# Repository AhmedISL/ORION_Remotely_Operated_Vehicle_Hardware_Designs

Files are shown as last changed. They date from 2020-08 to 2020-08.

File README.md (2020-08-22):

# ORION Remotely Operated Vehicle Hardware Design

These are the printed circuit boards (PCBs) designed for controlling the Remotely Operated Vehicle (ROV) which participated in the MATE international ROV competition 2019 and won the 7th place internationally and the 1st place locally and regionally.

## The electrical system is integrated using 4 main PCBs:
> ###### 1- **2** PCBs for the power management.
> ###### 2- **2** PCBs for the communication system and actuators' control.

***Power management PCBs' specifications:***
> ###### 1- Single layer.
> ###### 2- Voltage input range from 48V to 36V. 
> ###### 3- Over-current, voltage and thermal safety system

***Communication and actuators' control PCBs' specification:***
> ###### 1- Single layer.
> ###### 2- Voltage input range from 12V to 9V.
> ###### 3- The required voltage output with 99% efficiency
> ###### 4- Data transferring capability over Bluetooth/USB serial.

# Electronics' Enclosure Assembly
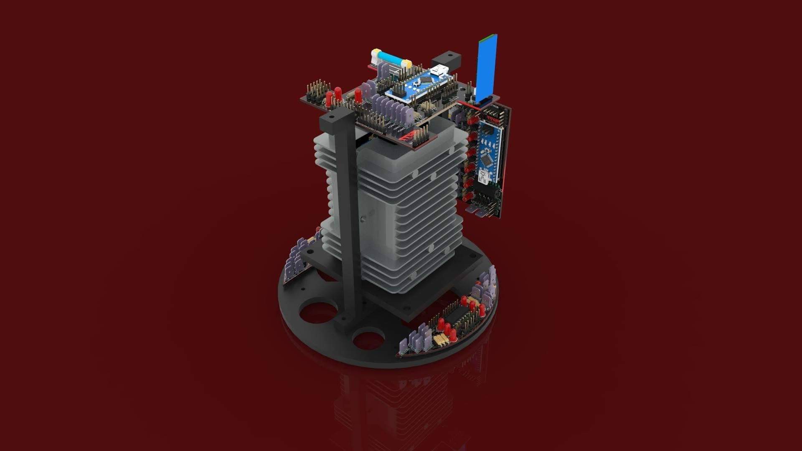
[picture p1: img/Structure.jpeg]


# Board I
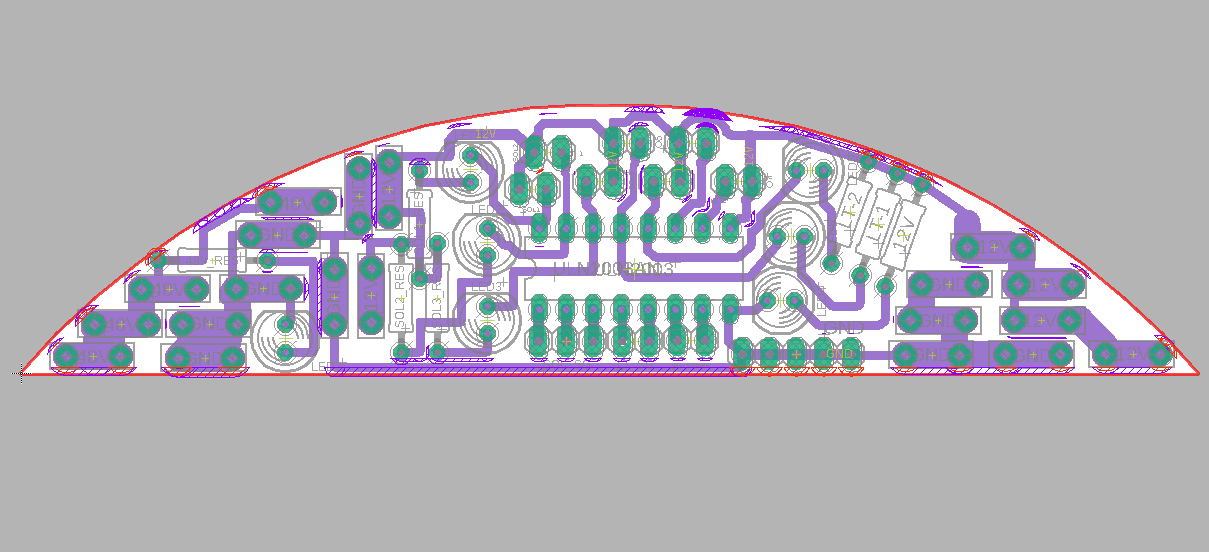
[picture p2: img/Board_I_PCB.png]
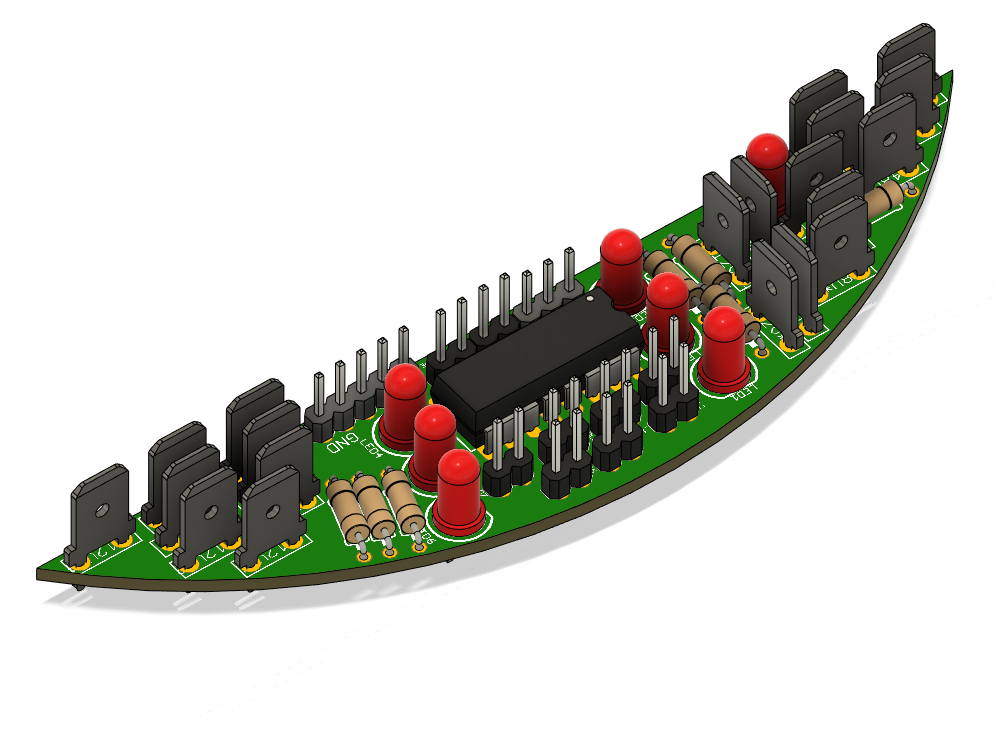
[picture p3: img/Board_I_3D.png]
 

# Board II
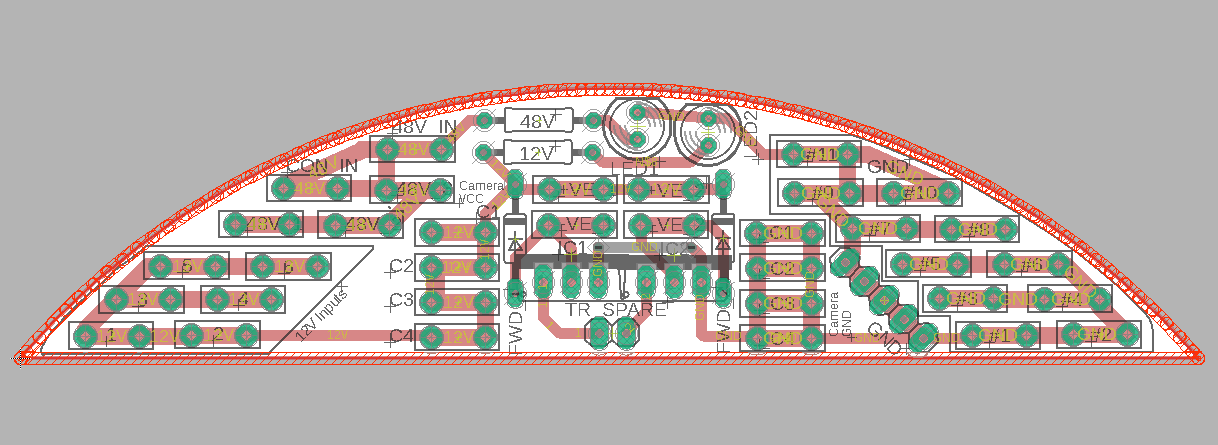
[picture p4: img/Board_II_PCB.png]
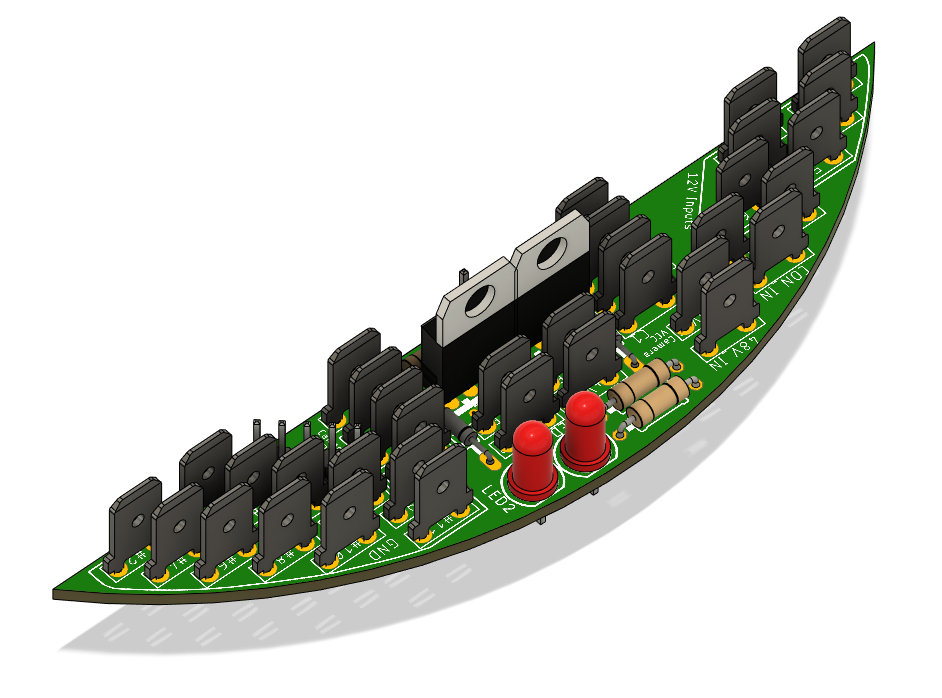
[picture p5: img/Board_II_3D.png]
 

# Board 2
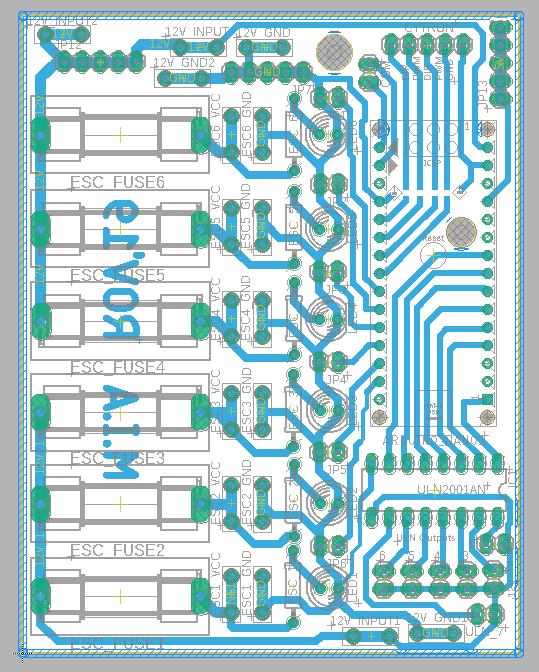
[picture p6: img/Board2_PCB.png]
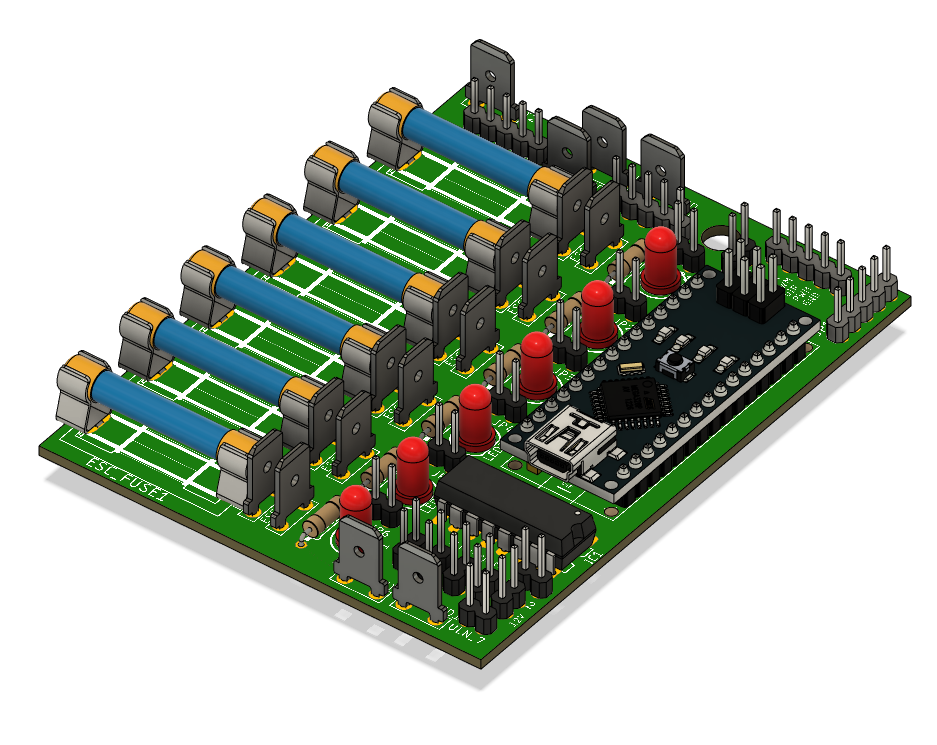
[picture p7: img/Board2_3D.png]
 

# Board 3
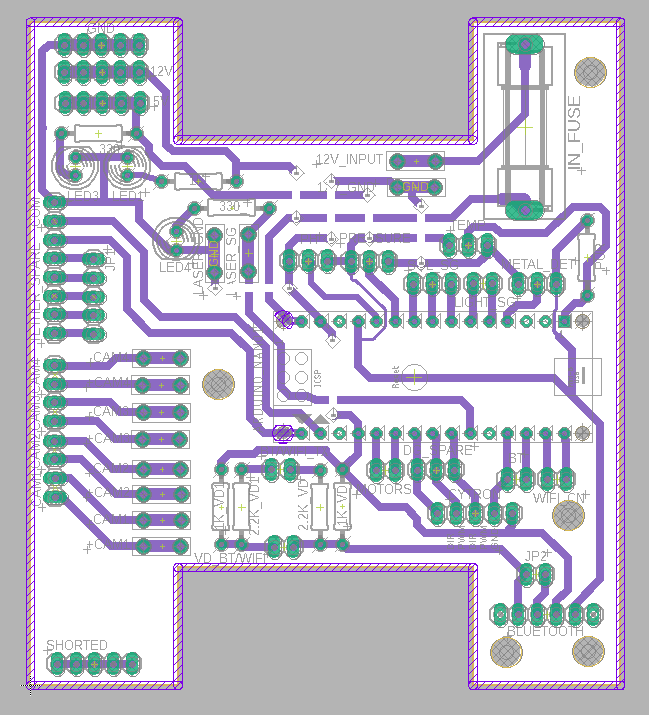
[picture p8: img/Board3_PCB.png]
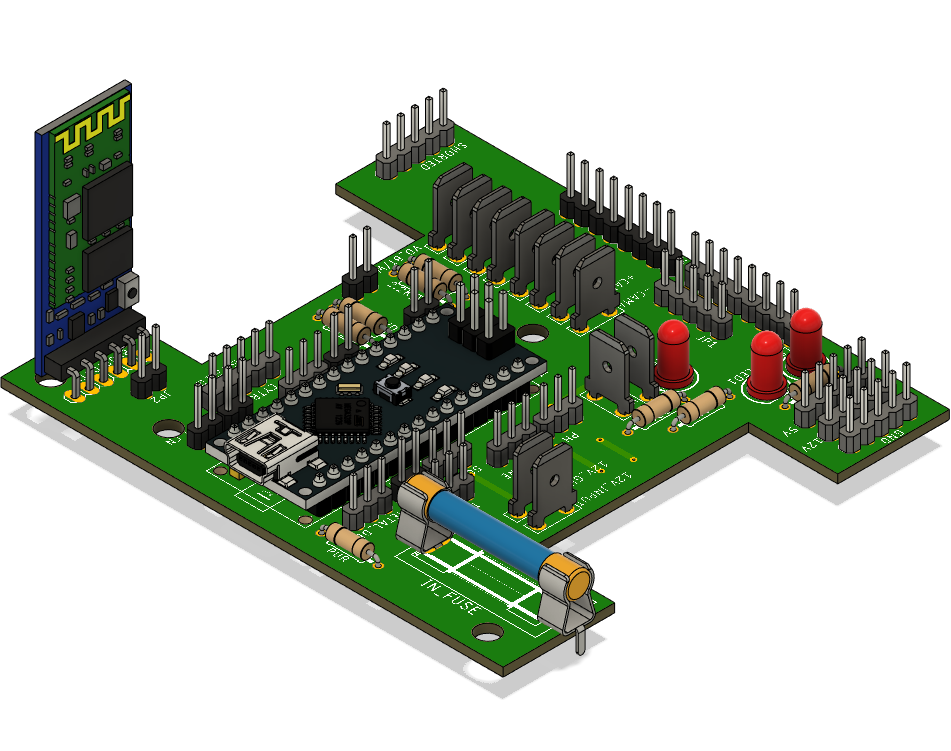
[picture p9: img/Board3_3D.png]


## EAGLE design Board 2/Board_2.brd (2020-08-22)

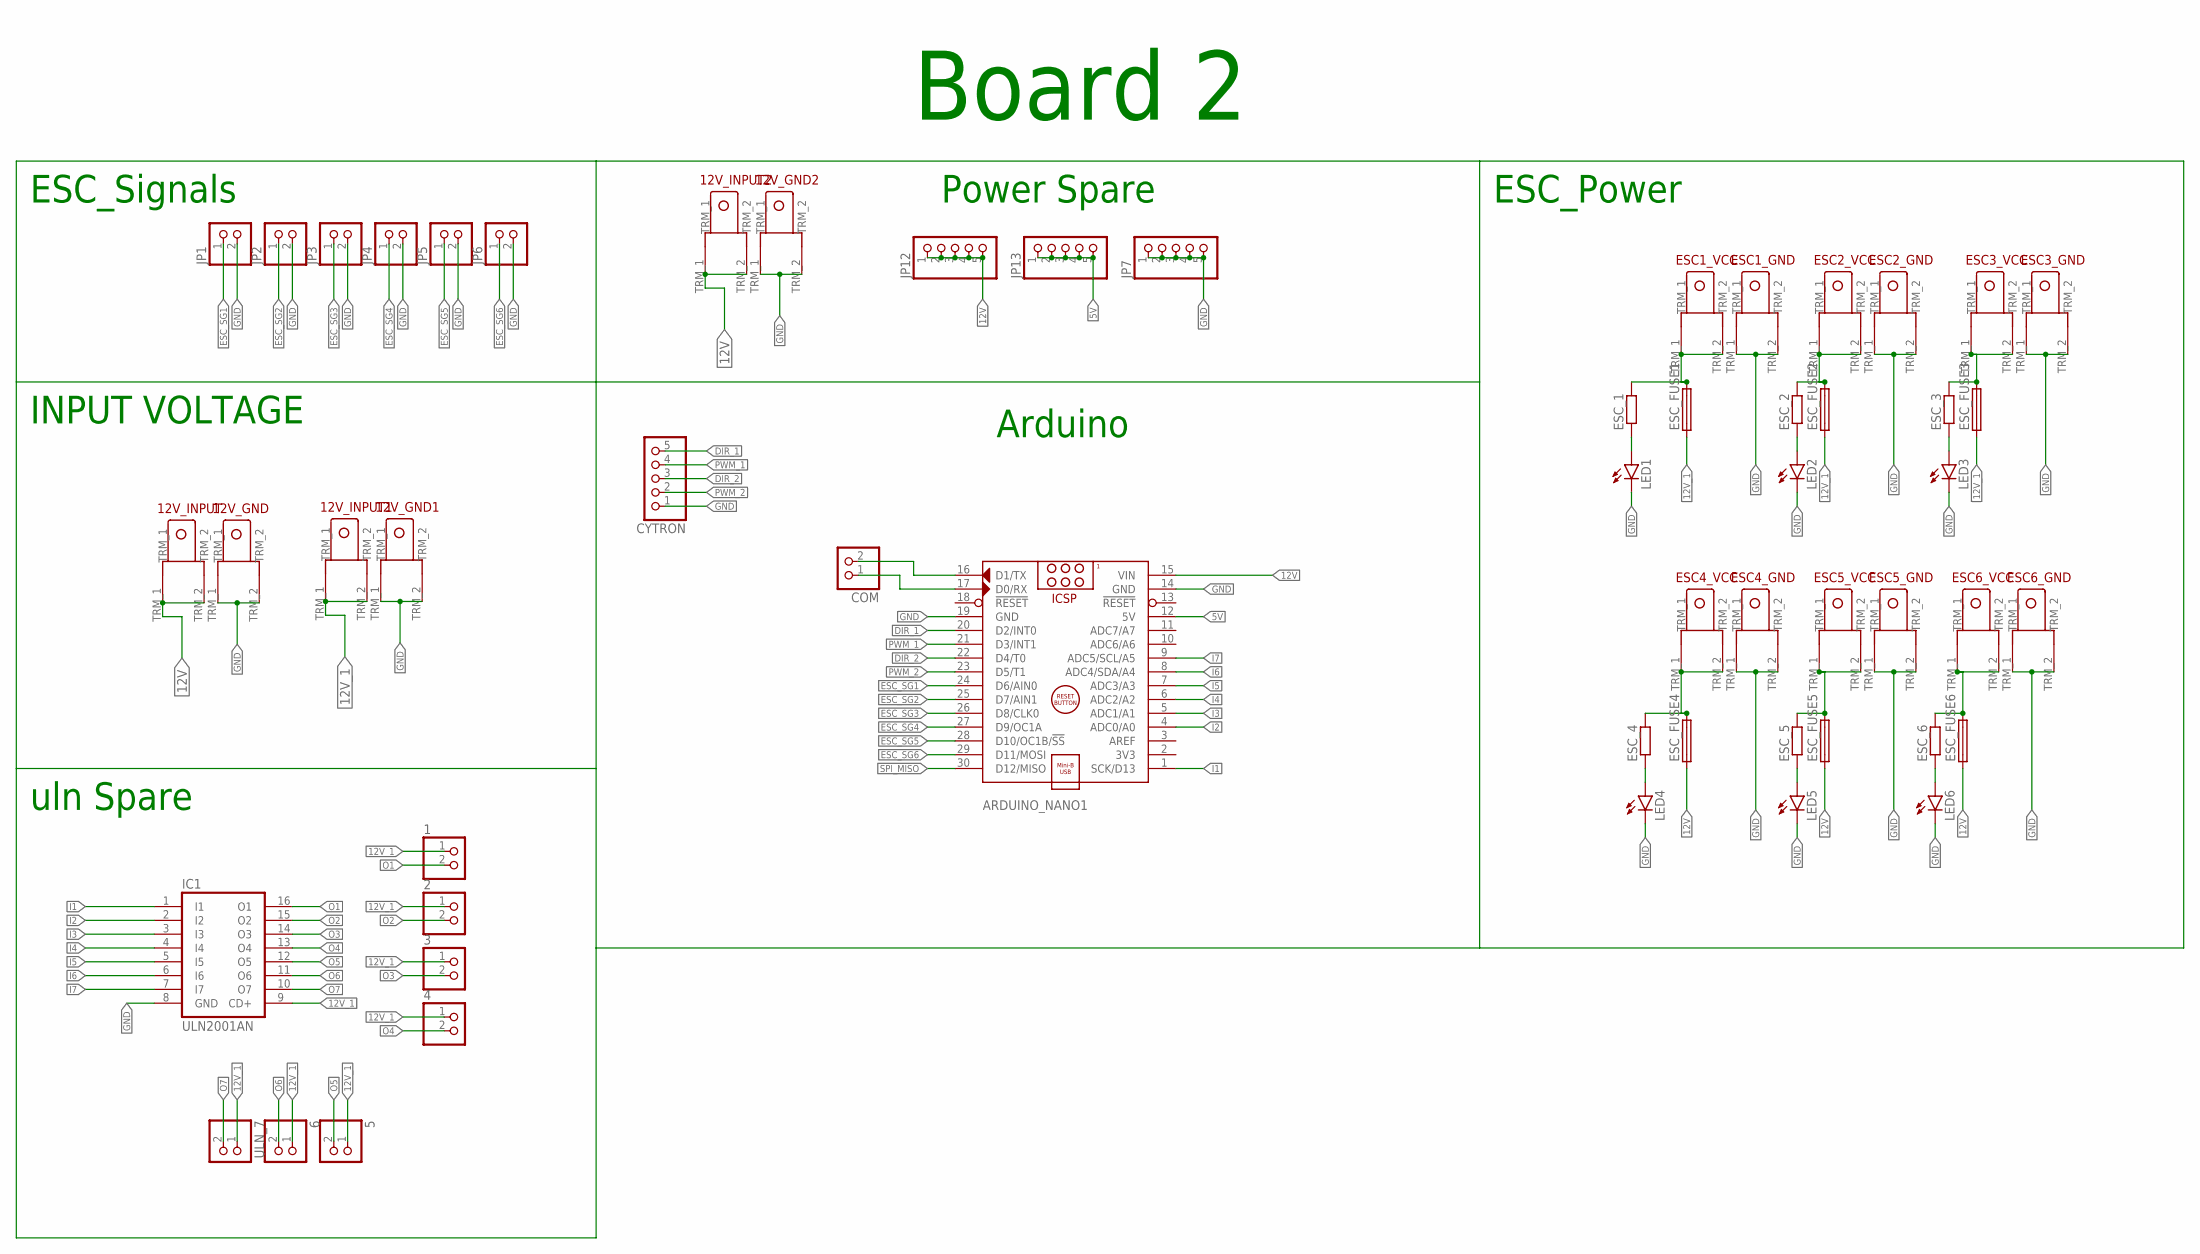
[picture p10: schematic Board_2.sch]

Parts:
1, 2, 3, 4, 5, 6: PINHD-1X2; 1X02
12V_GND, 12V_GND1, 12V_GND2, 12V_INPUT, 12V_INPUT1, 12V_INPUT2: TERMINAL_EDITED
ARDUINO_NANO1: ARDUINO_NANO
COM: PINHD-1X2; 1X02
CYTRON: PINHD-1X5; 1X05
ESC1_GND, ESC1_VCC, ESC2_GND, ESC2_VCC, ESC3_GND, ESC3_VCC, ESC4_GND, ESC4_VCC, ESC5_GND, ESC5_VCC, ESC6_GND, ESC6_VCC: TERMINAL_EDITED
ESC_1, ESC_2, ESC_3, ESC_4, ESC_5, ESC_6: RESISTOR; 0207/10
ESC_FUSE1, ESC_FUSE2, ESC_FUSE3, ESC_FUSE4, ESC_FUSE5, ESC_FUSE6: FUSE; SH22,5A
IC1: ULN2001AN; DIL16
JP1, JP2, JP3, JP4, JP5, JP6: PINHD-1X2; 1X02
JP7, JP12, JP13: PINHD-1X5; 1X05
LED1, LED2, LED3, LED4, LED5, LED6: LED5MM
ULN_7: PINHD-1X2; 1X02

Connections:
5V: ARDUINO_NANO1.12 (5V), JP13.1, JP13.2, JP13.3, JP13.4, JP13.5
12V: 12V_INPUT.TRM_1, 12V_INPUT.TRM_2, 12V_INPUT2.TRM_1, 12V_INPUT2.TRM_2, ARDUINO_NANO1.15 (VIN), ESC_FUSE4.1, ESC_FUSE5.1, ESC_FUSE6.1, JP12.1, JP12.2, JP12.3, JP12.4, JP12.5
12V_1: 1.1, 2.1, 3.1, 4.1, 5.1, 6.1, 12V_INPUT1.TRM_1, 12V_INPUT1.TRM_2, ESC_FUSE1.1, ESC_FUSE2.1, ESC_FUSE3.1, IC1.9 (CD+), ULN_7.1
DIR_1: ARDUINO_NANO1.20 (D2/INT0), CYTRON.5
DIR_2: ARDUINO_NANO1.22 (D4/T0), CYTRON.3
ESC_SG1: ARDUINO_NANO1.24 (D6/AIN0), JP1.1
ESC_SG2: ARDUINO_NANO1.25 (D7/AIN1), JP2.1
ESC_SG3: ARDUINO_NANO1.26 (D8/CLK0), JP3.1
ESC_SG4: ARDUINO_NANO1.27 (D9/OC1A), JP4.1
ESC_SG5: ARDUINO_NANO1.28 (D10/OC1B/!SS), JP5.1
ESC_SG6: ARDUINO_NANO1.29 (D11/MOSI), JP6.1
GND: 12V_GND.TRM_1, 12V_GND.TRM_2, 12V_GND1.TRM_1, 12V_GND1.TRM_2, 12V_GND2.TRM_1, 12V_GND2.TRM_2, ARDUINO_NANO1.14 (GND), ARDUINO_NANO1.19 (GND), CYTRON.1, ESC1_GND.TRM_1, ESC1_GND.TRM_2, ESC2_GND.TRM_1, ESC2_GND.TRM_2, ESC3_GND.TRM_1, ESC3_GND.TRM_2, ESC4_GND.TRM_1, ESC4_GND.TRM_2, ESC5_GND.TRM_1, ESC5_GND.TRM_2, ESC6_GND.TRM_1, ESC6_GND.TRM_2, IC1.8 (GND), JP1.2, JP2.2, JP3.2, JP4.2, JP5.2, JP6.2, JP7.1, JP7.2, JP7.3, JP7.4, JP7.5, LED1.K (C), LED2.K (C), LED3.K (C), LED4.K (C), LED5.K (C), LED6.K (C)
I1: ARDUINO_NANO1.1 (SCK/D13), IC1.1 (I1)
I2: ARDUINO_NANO1.4 (ADC0/A0), IC1.2 (I2)
I3: ARDUINO_NANO1.5 (ADC1/A1), IC1.3 (I3)
I4: ARDUINO_NANO1.6 (ADC2/A2), IC1.4 (I4)
I5: ARDUINO_NANO1.7 (ADC3/A3), IC1.5 (I5)
I6: ARDUINO_NANO1.8 (ADC4/SDA/A4), IC1.6 (I6)
I7: ARDUINO_NANO1.9 (ADC5/SCL/A5), IC1.7 (I7)
unnamed: ESC1_VCC.TRM_1, ESC1_VCC.TRM_2, ESC_1.2, ESC_FUSE1.2
unnamed: ESC2_VCC.TRM_1, ESC2_VCC.TRM_2, ESC_2.2, ESC_FUSE2.2
unnamed: ARDUINO_NANO1.17 (D0/RX), COM.1
unnamed: ARDUINO_NANO1.16 (D1/TX), COM.2
unnamed: ESC3_VCC.TRM_1, ESC3_VCC.TRM_2, ESC_3.2, ESC_FUSE3.2
unnamed: ESC4_VCC.TRM_1, ESC4_VCC.TRM_2, ESC_4.2, ESC_FUSE4.2
unnamed: ESC_1.1, LED1.A
unnamed: ESC5_VCC.TRM_1, ESC5_VCC.TRM_2, ESC_5.2, ESC_FUSE5.2
unnamed: ESC_2.1, LED2.A
unnamed: ESC6_VCC.TRM_1, ESC6_VCC.TRM_2, ESC_6.2, ESC_FUSE6.2
unnamed: ESC_3.1, LED3.A
unnamed: ESC_4.1, LED4.A
unnamed: ESC_5.1, LED5.A
unnamed: ESC_6.1, LED6.A
O1: 1.2, IC1.16 (O1)
O2: 2.2, IC1.15 (O2)
O3: 3.2, IC1.14 (O3)
O4: 4.2, IC1.13 (O4)
O5: 5.2, IC1.12 (O5)
O6: 6.2, IC1.11 (O6)
O7: IC1.10 (O7), ULN_7.2
PWM_1: ARDUINO_NANO1.21 (D3/INT1), CYTRON.4
PWM_2: ARDUINO_NANO1.23 (D5/T1), CYTRON.2
SPI_MISO: ARDUINO_NANO1.30 (D12/MISO)

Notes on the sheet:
ESC_Signals
uln Spare
INPUT VOLTAGE
Arduino
Power Spare
ESC_Power
Board 2

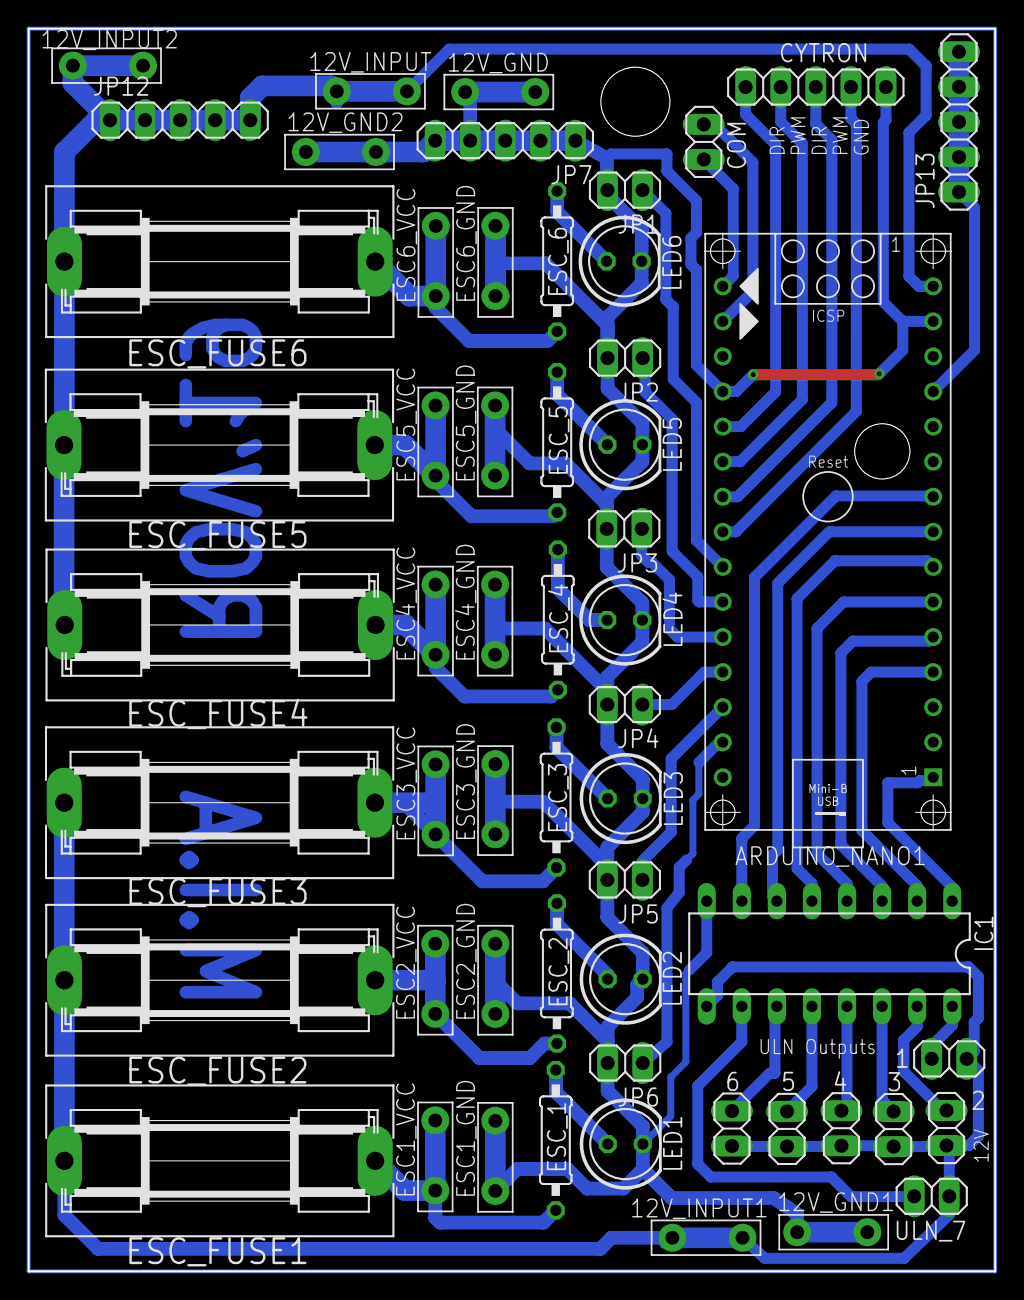
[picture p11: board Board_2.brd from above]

Board: 2 copper layers, 70.0 x 90.0 mm, 56 parts (0 on the bottom side), 42 nets.

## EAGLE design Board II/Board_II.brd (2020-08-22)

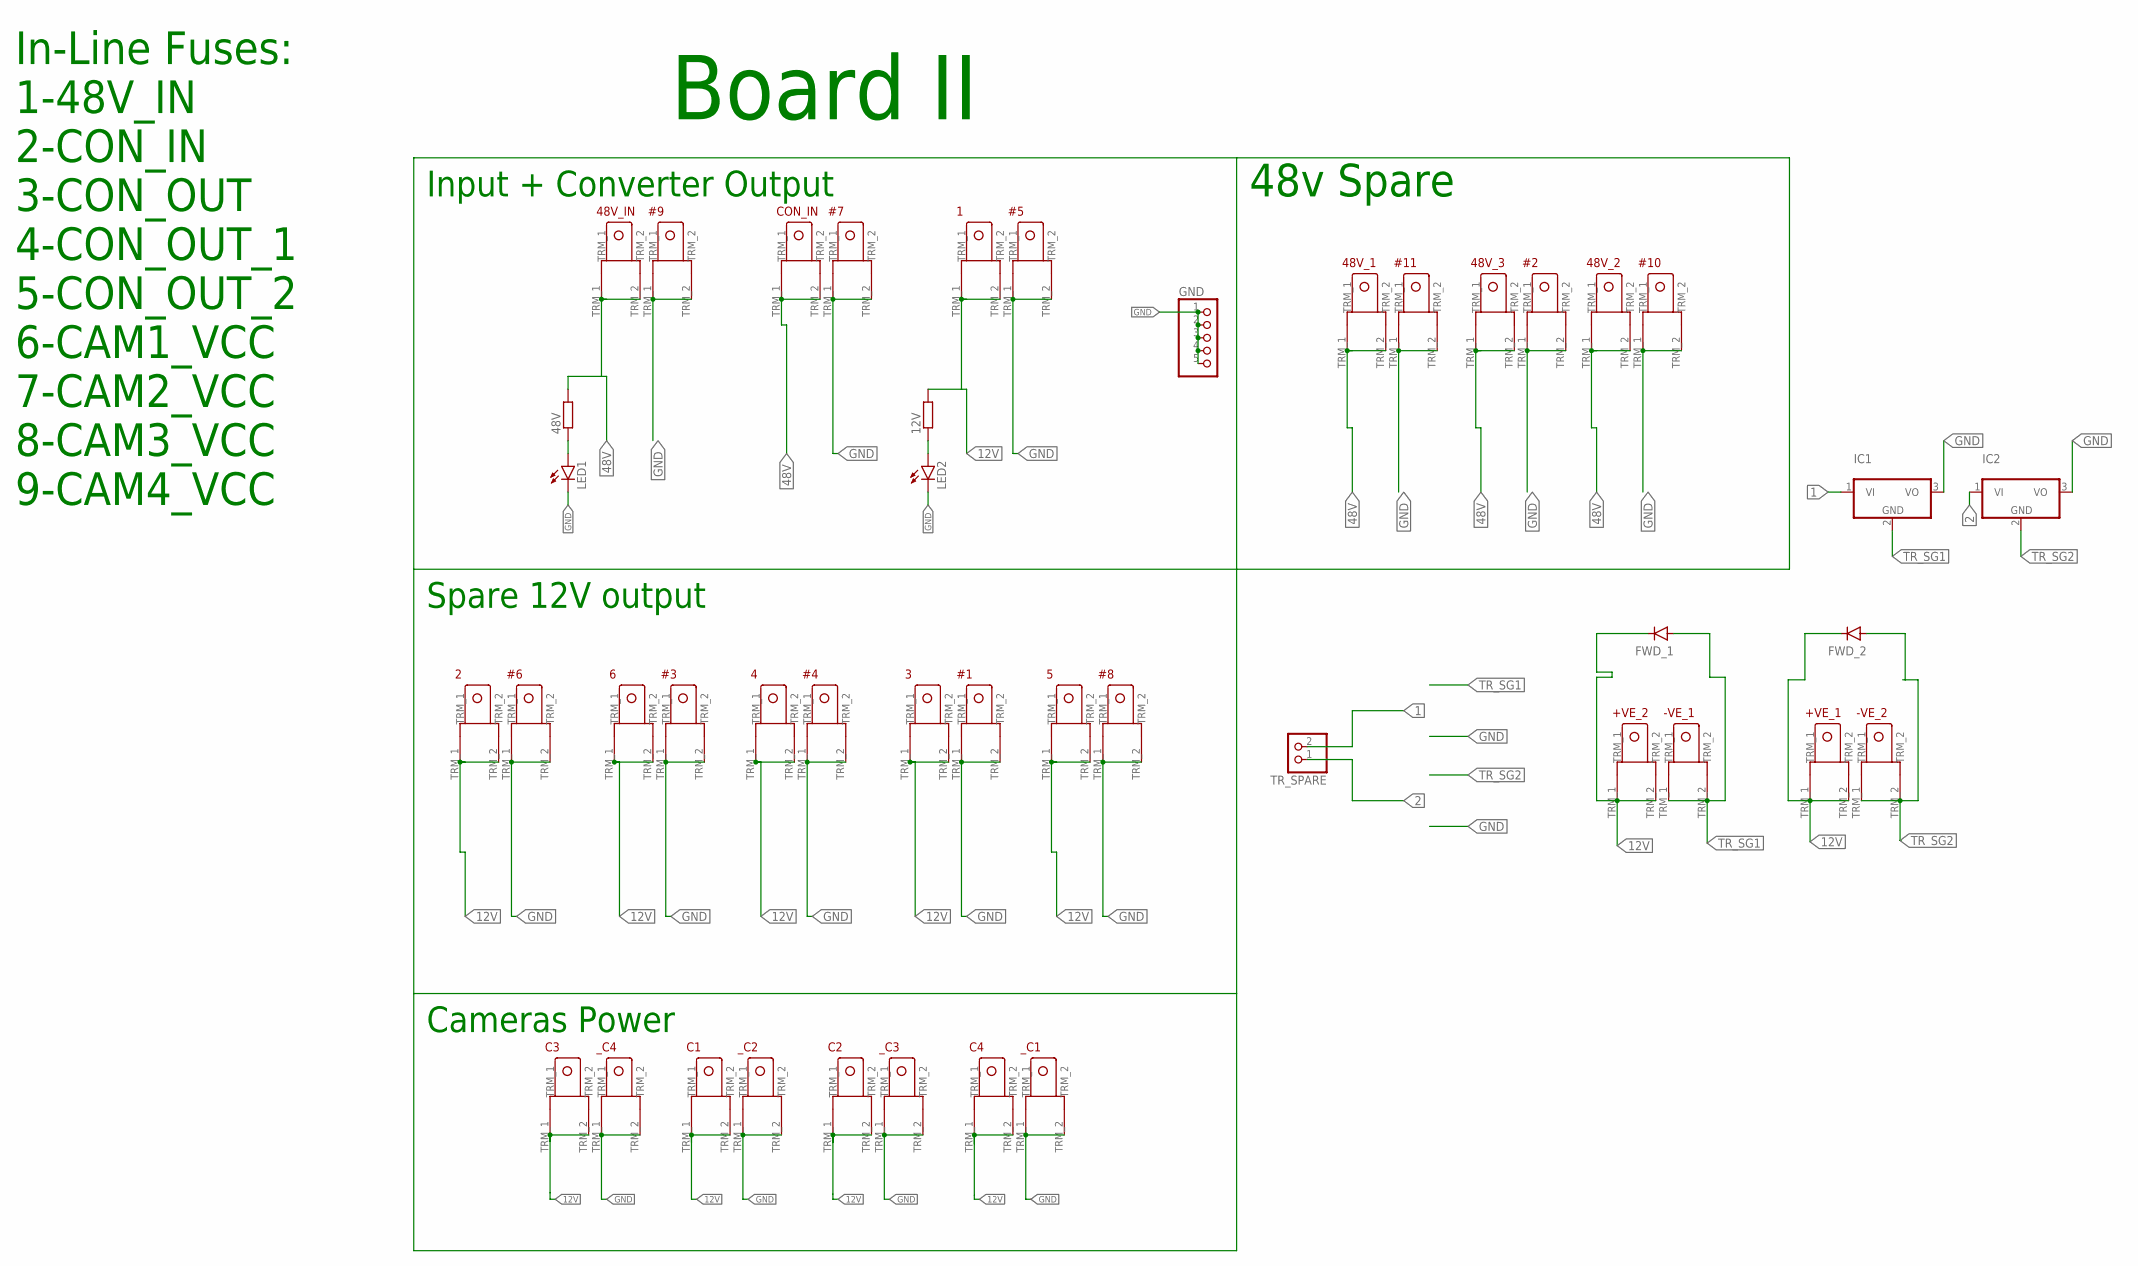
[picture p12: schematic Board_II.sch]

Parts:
1, 2, 3, 4, 5, 6, 48V_1, 48V_2, 48V_3, 48V_IN: TERMINAL_EDITED
12V, 48V: RESISTOR; 0207/10
#1, #2, #3, #4, #5, #6, #7, #8, #9, #10, #11: TERMINAL_EDITED
+VE_1, +VE_2: TERMINAL_EDITED
-VE_1, -VE_2: TERMINAL_EDITED
C1, C2, C3, C4: TERMINAL_EDITED
CON_IN: TERMINAL_EDITED
FWD_1, FWD_2: DIODE; DO35-10
GND: PINHD-1X5; 1X05
IC1, IC2: 7805_REG; TO220V
LED1, LED2: LED5MM
TR_SPARE: PINHD-1X2; 1X02
_C1, _C2, _C3, _C4: TERMINAL_EDITED

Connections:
1: IC1.1 (VI), TR_SPARE.2
2: IC2.1 (VI), TR_SPARE.1
12V: 1.TRM_1, 1.TRM_2, 2.TRM_1, 2.TRM_2, 3.TRM_1, 3.TRM_2, 4.TRM_1, 4.TRM_2, 5.TRM_1, 5.TRM_2, 6.TRM_1, 6.TRM_2, 12V.2, +VE_1.TRM_1, +VE_1.TRM_2, +VE_2.TRM_1, +VE_2.TRM_2, C1.TRM_1, C1.TRM_2, C2.TRM_1, C2.TRM_2, C3.TRM_1, C3.TRM_2, C4.TRM_1, C4.TRM_2, FWD_1.C, FWD_2.C
48V: 48V.2, 48V_1.TRM_1, 48V_1.TRM_2, 48V_2.TRM_1, 48V_2.TRM_2, 48V_3.TRM_1, 48V_3.TRM_2, 48V_IN.TRM_1, 48V_IN.TRM_2, CON_IN.TRM_1, CON_IN.TRM_2
GND: #1.TRM_1, #1.TRM_2, #2.TRM_1, #2.TRM_2, #3.TRM_1, #3.TRM_2, #4.TRM_1, #4.TRM_2, #5.TRM_1, #5.TRM_2, #6.TRM_1, #6.TRM_2, #7.TRM_1, #7.TRM_2, #8.TRM_1, #8.TRM_2, #9.TRM_1, #9.TRM_2, #10.TRM_1, #10.TRM_2, #11.TRM_1, #11.TRM_2, GND.1, GND.2, GND.3, GND.4, GND.5, IC1.3 (VO), IC2.3 (VO), LED1.K (C), LED2.K (C), _C1.TRM_1, _C1.TRM_2, _C2.TRM_1, _C2.TRM_2, _C3.TRM_1, _C3.TRM_2, _C4.TRM_1, _C4.TRM_2
unnamed: 48V.1, LED1.A
unnamed: 12V.1, LED2.A
TR_SG1: -VE_1.TRM_1, -VE_1.TRM_2, FWD_1.A, IC1.2 (GND)
TR_SG2: -VE_2.TRM_1, -VE_2.TRM_2, FWD_2.A, IC2.2 (GND)

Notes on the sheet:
Input + Converter Output
Spare 12V output
Cameras Power
Board II
In-Line Fuses: 1-48V_IN 2-CON_IN 3-CON_OUT 4-CON_OUT_1 5-CON_OUT_2 6-CAM1_VCC 7-CAM2_VCC 8-CAM3_VCC 9-CAM4_VCC
48v Spare

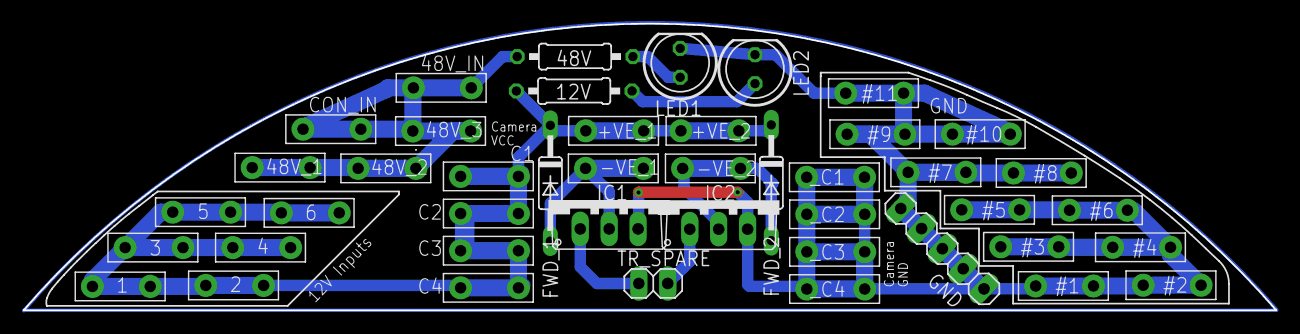
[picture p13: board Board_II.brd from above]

Board: 2 copper layers, 110.0 x 25.2 mm, 44 parts (0 on the bottom side), 9 nets.

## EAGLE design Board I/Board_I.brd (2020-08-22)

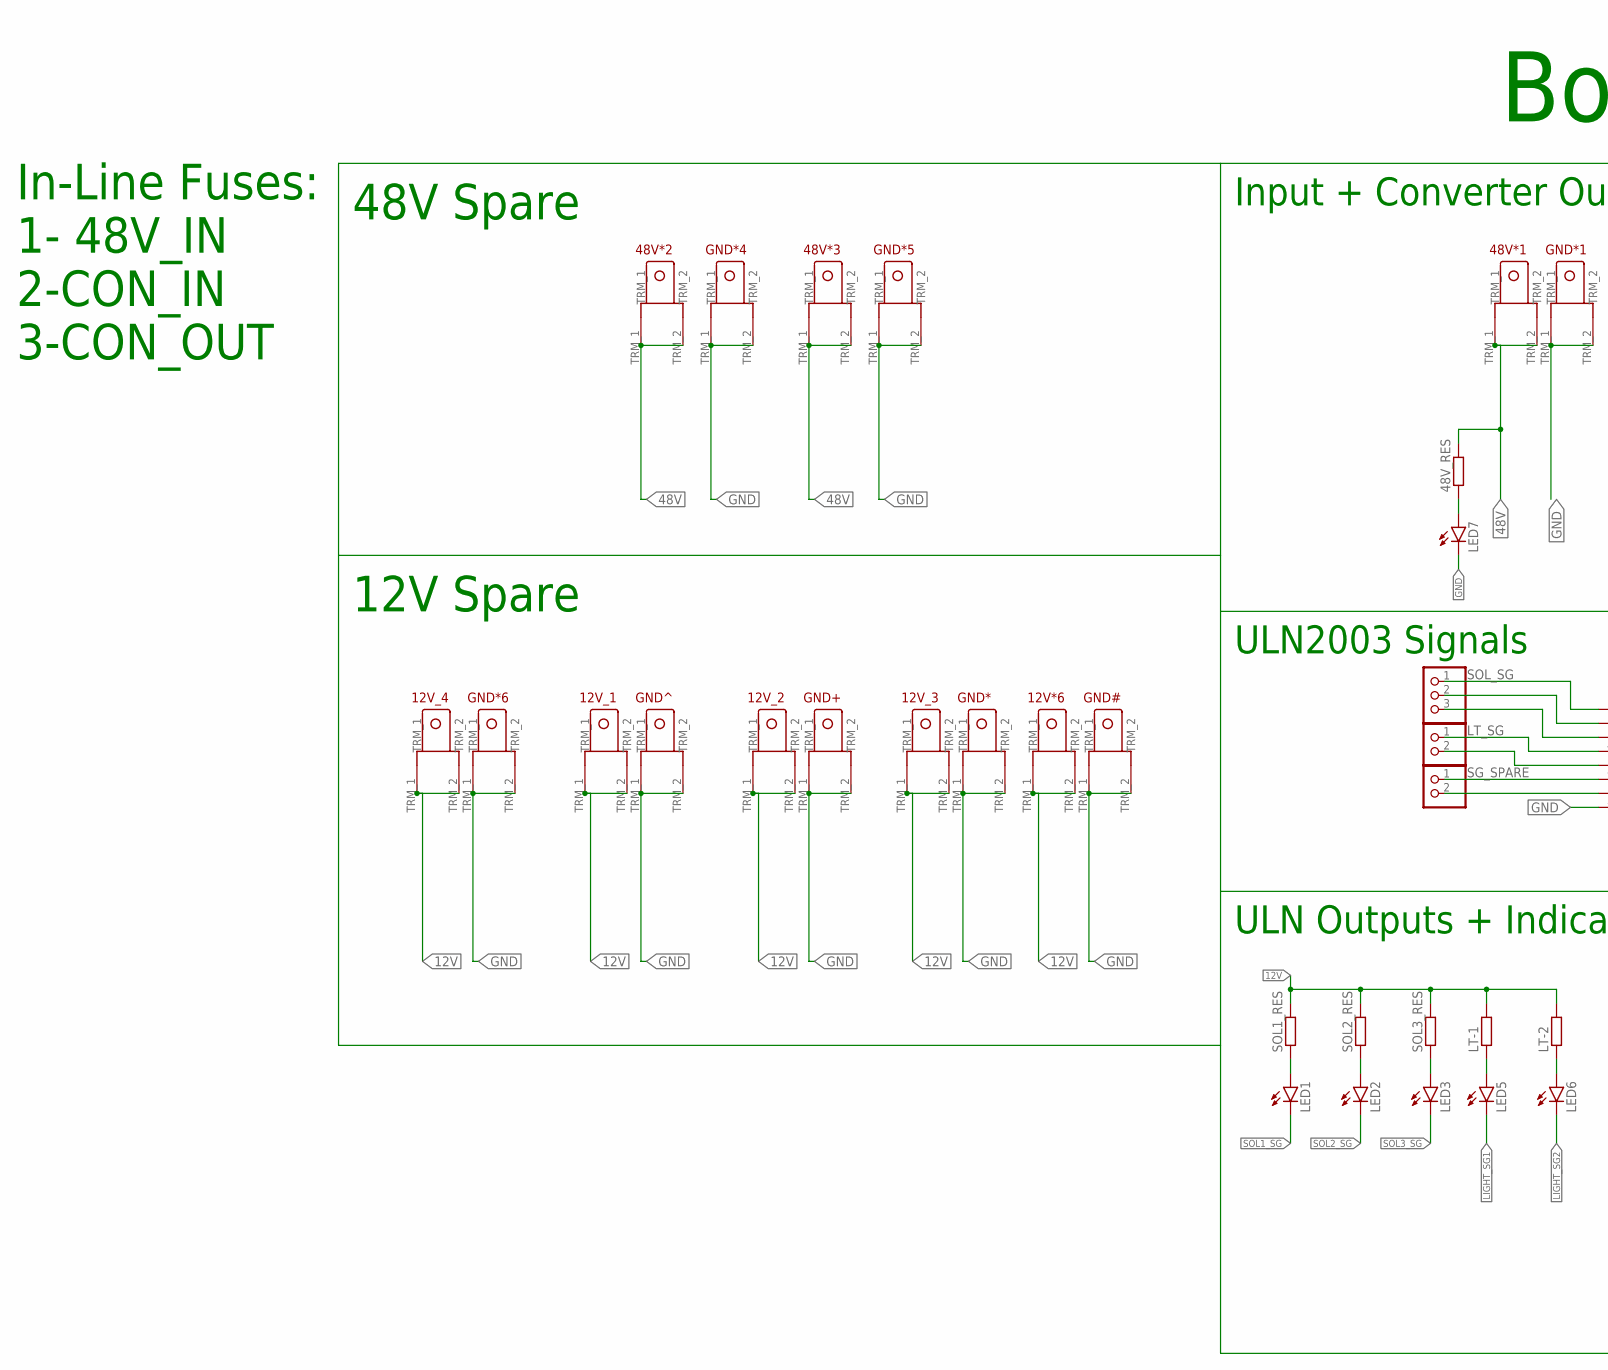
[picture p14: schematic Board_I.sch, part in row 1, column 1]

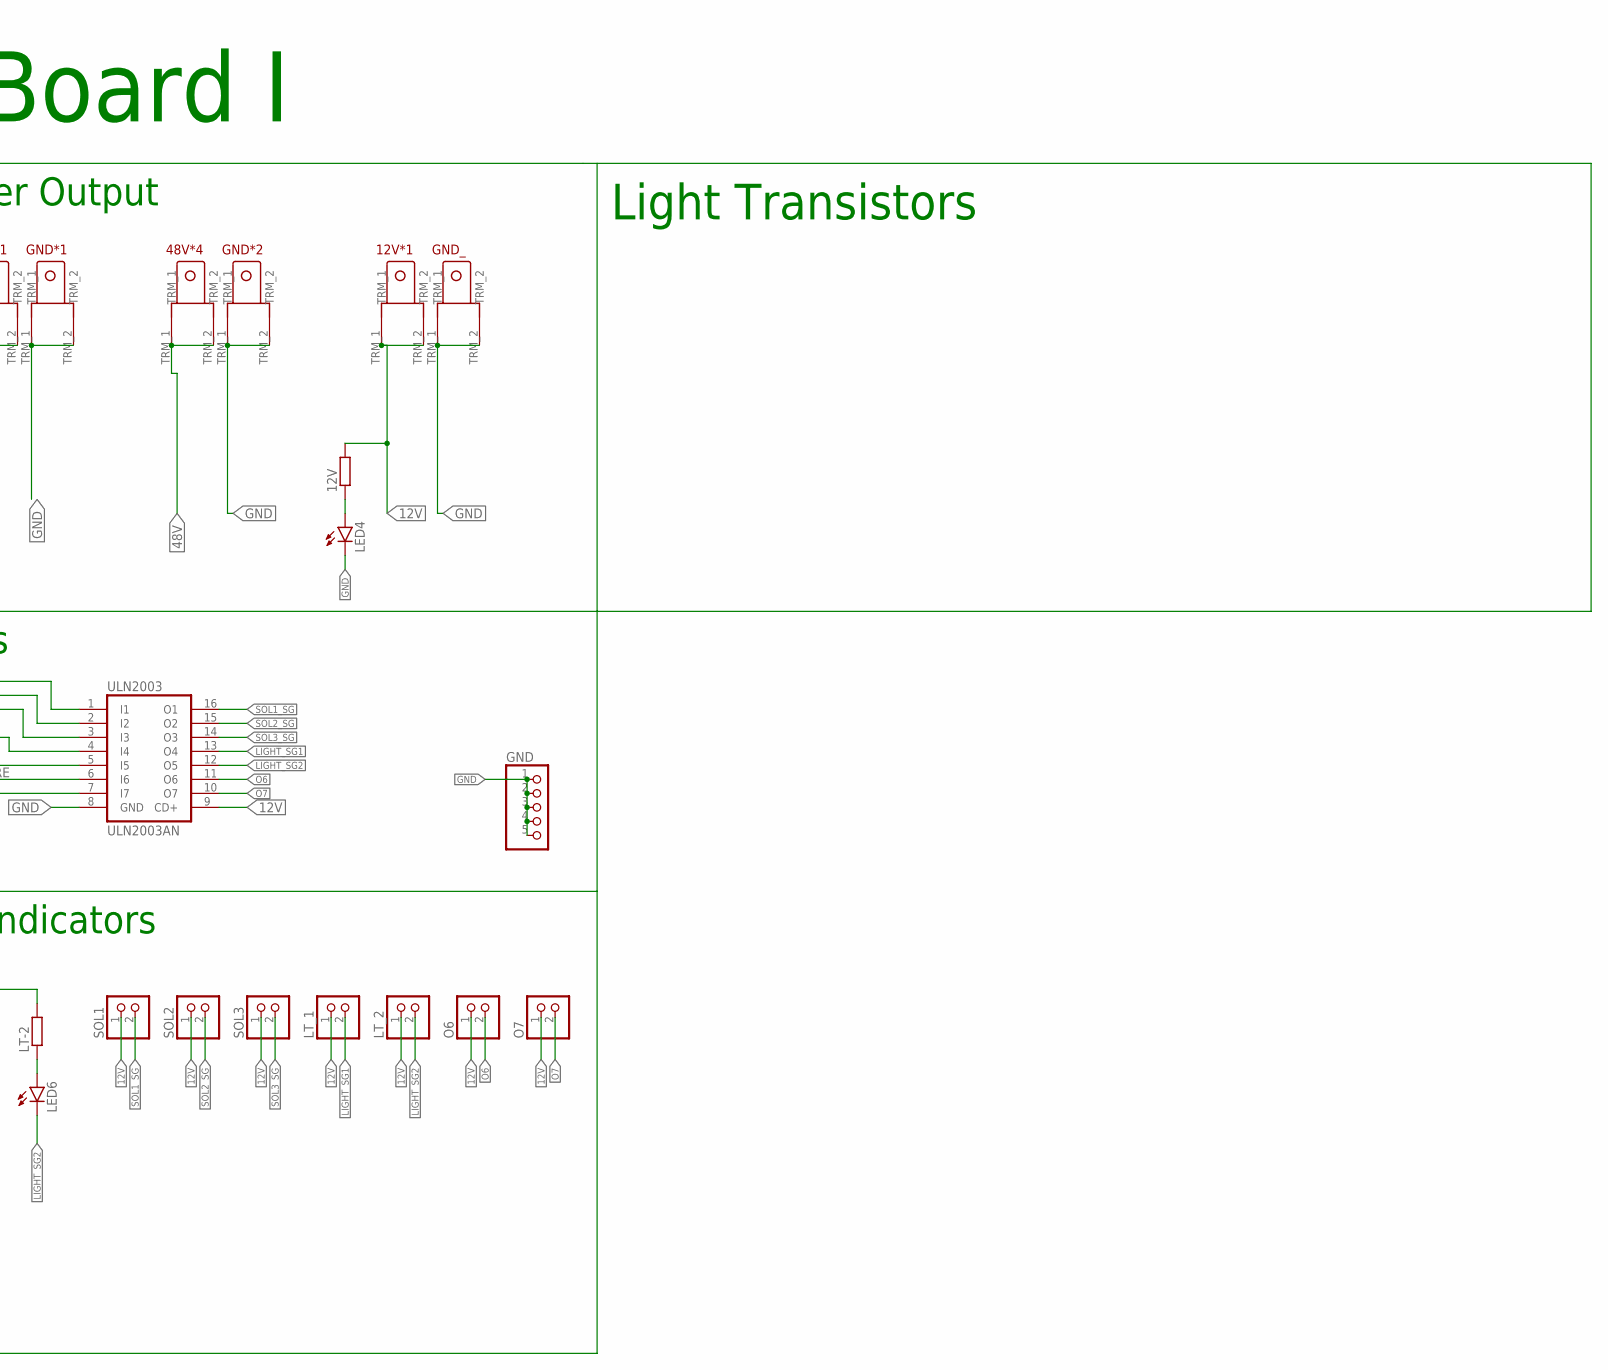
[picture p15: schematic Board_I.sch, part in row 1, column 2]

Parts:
12V, 48V_RES: RESISTOR; 0207/10
12V*1, 12V*6, 12V_1, 12V_2, 12V_3, 12V_4, 48V*1, 48V*2, 48V*3, 48V*4: TERMINAL_EDITED
GND: PINHD-1X5; 1X05
GND#: TERMINAL_EDITED
GND*, GND*1, GND*2, GND*4, GND*5, GND*6: TERMINAL_EDITED
GND+: TERMINAL_EDITED
GND^: TERMINAL_EDITED
GND_: TERMINAL_EDITED
LED1, LED2, LED3, LED4, LED5, LED6, LED7: LED5MM
LT-1, LT-2: RESISTOR; 0207/10
LT_1, LT_2: PINHD-1X2; 1X02
LT_SG: PINHD-1X2; 1X02
O6, O7: PINHD-1X2; 1X02
SG_SPARE: PINHD-1X2; 1X02
SOL1, SOL2, SOL3: PINHD-1X2; 1X02
SOL1_RES, SOL2_RES, SOL3_RES: RESISTOR; 0207/10
SOL_SG: PINHD-1X3; 1X03
ULN2003: ULN2003AN; DIL16

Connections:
12V: 12V.2, 12V*1.TRM_1, 12V*1.TRM_2, 12V*6.TRM_1, 12V*6.TRM_2, 12V_1.TRM_1, 12V_1.TRM_2, 12V_2.TRM_1, 12V_2.TRM_2, 12V_3.TRM_1, 12V_3.TRM_2, 12V_4.TRM_1, 12V_4.TRM_2, LT-1.2, LT-2.2, LT_1.1, LT_2.1, O6.1, O7.1, SOL1.1, SOL1_RES.2, SOL2.1, SOL2_RES.2, SOL3.1, SOL3_RES.2, ULN2003.9 (CD+)
48V: 48V*1.TRM_1, 48V*1.TRM_2, 48V*2.TRM_1, 48V*2.TRM_2, 48V*3.TRM_1, 48V*3.TRM_2, 48V*4.TRM_1, 48V*4.TRM_2, 48V_RES.2
GND: GND.1, GND.2, GND.3, GND.4, GND.5, GND#.TRM_1, GND#.TRM_2, GND*.TRM_1, GND*.TRM_2, GND*1.TRM_1, GND*1.TRM_2, GND*2.TRM_1, GND*2.TRM_2, GND*4.TRM_1, GND*4.TRM_2, GND*5.TRM_1, GND*5.TRM_2, GND*6.TRM_1, GND*6.TRM_2, GND+.TRM_1, GND+.TRM_2, GND^.TRM_1, GND^.TRM_2, GND_.TRM_1, GND_.TRM_2, LED4.K (C), LED7.K (C), ULN2003.8 (GND)
LIGHT_SG1: LED5.K (C), LT_1.2, ULN2003.13 (O4)
LIGHT_SG2: LED6.K (C), LT_2.2, ULN2003.12 (O5)
unnamed: LED6.A, LT-2.1
unnamed: SOL_SG.1, ULN2003.1 (I1)
unnamed: 48V_RES.1, LED7.A
unnamed: SOL_SG.2, ULN2003.2 (I2)
unnamed: 12V.1, LED4.A
unnamed: SOL_SG.3, ULN2003.3 (I3)
unnamed: LED1.A, SOL1_RES.1
unnamed: LED2.A, SOL2_RES.1
unnamed: LED3.A, SOL3_RES.1
unnamed: LT_SG.1, ULN2003.4 (I4)
unnamed: LT_SG.2, ULN2003.5 (I5)
unnamed: SG_SPARE.1, ULN2003.6 (I6)
unnamed: SG_SPARE.2, ULN2003.7 (I7)
unnamed: LED5.A, LT-1.1
O6: O6.2, ULN2003.11 (O6)
O7: O7.2, ULN2003.10 (O7)
SOL1_SG: LED1.K (C), SOL1.2, ULN2003.16 (O1)
SOL2_SG: LED2.K (C), SOL2.2, ULN2003.15 (O2)
SOL3_SG: LED3.K (C), SOL3.2, ULN2003.14 (O3)

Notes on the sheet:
Input + Converter Output
ULN2003 Signals
ULN Outputs + Indicators
Board I
In-Line Fuses: 1- 48V_IN 2-CON_IN 3-CON_OUT
48V Spare
12V Spare
Light Transistors

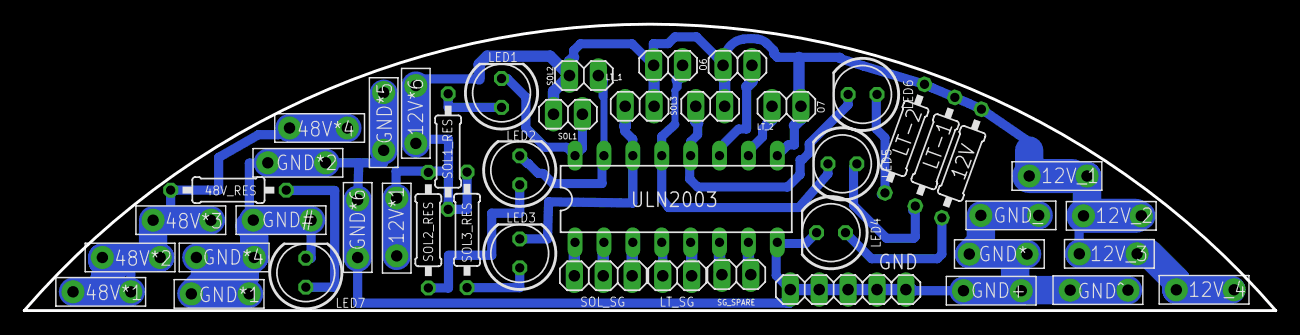
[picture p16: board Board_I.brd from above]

Board: 2 copper layers, 110.0 x 25.2 mm, 46 parts (0 on the bottom side), 24 nets.

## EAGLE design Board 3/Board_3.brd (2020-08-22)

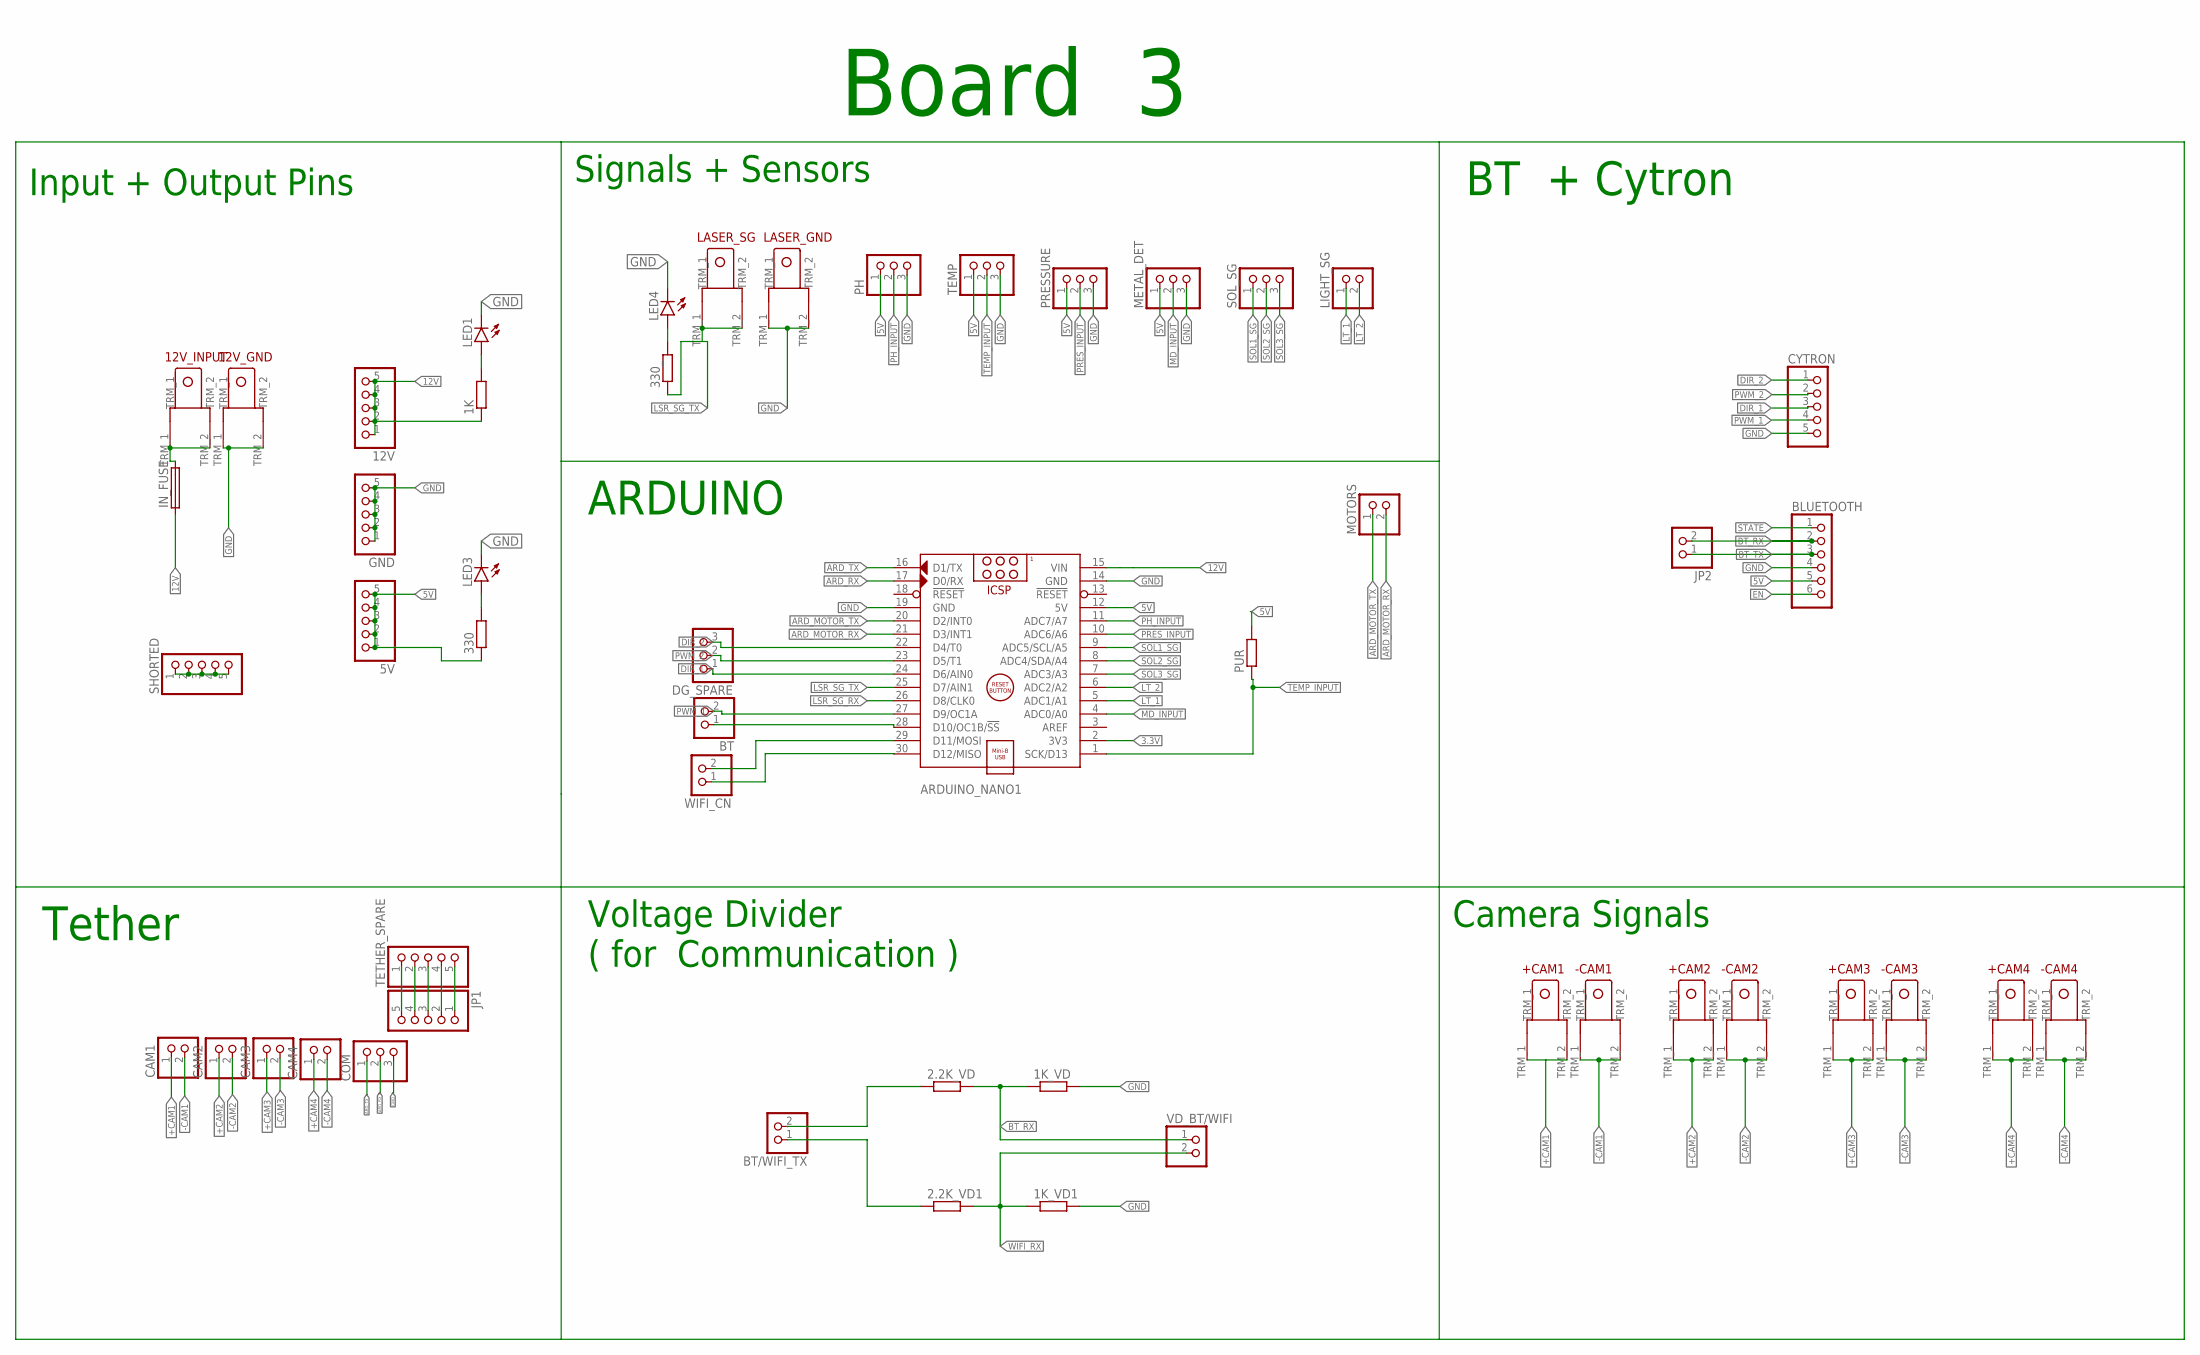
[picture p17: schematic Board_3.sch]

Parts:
1K, 1K_VD, 1K_VD1, 2.2K_VD, 2.2K_VD1, 330, 330_: RESISTOR; 0207/10
5V, 12V: PINHD-1X5; 1X05
12V_GND, 12V_INPUT: TERMINAL_EDITED
+CAM1, +CAM2, +CAM3, +CAM4: TERMINAL_EDITED
-CAM1, -CAM2, -CAM3, -CAM4: TERMINAL_EDITED
ARDUINO_NANO1: ARDUINO_NANO
BLUETOOTH: BLUETOOTH_HC-05; 1X06
BT: PINHD-1X2; 1X02
BT/WIFI_TX: PINHD-1X2; 1X02
CAM1, CAM2, CAM3, CAM4: PINHD-1X2; 1X02
COM: PINHD-1X3; 1X03
CYTRON: PINHD-1X5; 1X05
DG_SPARE: PINHD-1X3; 1X03
GND: PINHD-1X5; 1X05
IN_FUSE: FUSE; SH22,5A
JP1: PINHD-1X5; 1X05
JP2: PINHD-1X2; 1X02
LASER_GND: TERMINAL_EDITED
LASER_SG: TERMINAL_EDITED
LED1, LED3, LED4: LED5MM
LIGHT_SG: PINHD-1X2; 1X02
METAL_DET: PINHD-1X3; 1X03
MOTORS: PINHD-1X2; 1X02
PH: PINHD-1X3; 1X03
PRESSURE: PINHD-1X3; 1X03
PUR: RESISTOR; 0207/10
SHORTED: PINHD-1X5; 1X05
SOL_SG: PINHD-1X3; 1X03
TEMP: PINHD-1X3; 1X03
TETHER_SPARE: PINHD-1X5; 1X05
VD_BT/WIFI: PINHD-1X2; 1X02
WIFI_CN: PINHD-1X2; 1X02

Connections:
3.3V: ARDUINO_NANO1.2 (3V3)
5V: 5V.1, 5V.2, 5V.3, 5V.4, 5V.5, 330.1, ARDUINO_NANO1.12 (5V), BLUETOOTH.5, METAL_DET.1, PH.1, PRESSURE.1, PUR.2, TEMP.1
12V: 1K.1, 12V.1, 12V.2, 12V.3, 12V.4, 12V.5, ARDUINO_NANO1.15 (VIN), IN_FUSE.1
+CAM1: +CAM1.TRM_1, +CAM1.TRM_2, CAM1.1
+CAM2: +CAM2.TRM_1, +CAM2.TRM_2, CAM2.1
+CAM3: +CAM3.TRM_1, +CAM3.TRM_2, CAM3.1
+CAM4: +CAM4.TRM_1, +CAM4.TRM_2, CAM4.1
-CAM1: -CAM1.TRM_1, -CAM1.TRM_2, CAM1.2
-CAM2: -CAM2.TRM_1, -CAM2.TRM_2, CAM2.2
-CAM3: -CAM3.TRM_1, -CAM3.TRM_2, CAM3.2
-CAM4: -CAM4.TRM_1, -CAM4.TRM_2, CAM4.2
ARD_MOTOR_RX: ARDUINO_NANO1.21 (D3/INT1), MOTORS.2
ARD_MOTOR_TX: ARDUINO_NANO1.20 (D2/INT0), MOTORS.1
ARD_RX: ARDUINO_NANO1.17 (D0/RX), COM.2
ARD_TX: ARDUINO_NANO1.16 (D1/TX), COM.1
BT_RX: 1K_VD.1, 2.2K_VD.2, BLUETOOTH.2, JP2.2, VD_BT/WIFI.1
BT_TX: BLUETOOTH.3, JP2.1
DIR_1: ARDUINO_NANO1.24 (D6/AIN0), CYTRON.3, DG_SPARE.1
DIR_2: ARDUINO_NANO1.22 (D4/T0), CYTRON.1, DG_SPARE.3
EN: BLUETOOTH.6
GND: 1K_VD.2, 1K_VD1.2, 12V_GND.TRM_1, 12V_GND.TRM_2, ARDUINO_NANO1.14 (GND), ARDUINO_NANO1.19 (GND), BLUETOOTH.4, COM.3, CYTRON.5, GND.1, GND.2, GND.3, GND.4, GND.5, LASER_GND.TRM_1, LASER_GND.TRM_2, LED1.K (C), LED3.K (C), LED4.K (C), METAL_DET.3, PH.3, PRESSURE.3, TEMP.3
LSR_SG_RX: ARDUINO_NANO1.26 (D8/CLK0)
LSR_SG_TX: 330_.1, ARDUINO_NANO1.25 (D7/AIN1), LASER_SG.TRM_1, LASER_SG.TRM_2
LT_1: ARDUINO_NANO1.5 (ADC1/A1), LIGHT_SG.1
LT_2: ARDUINO_NANO1.6 (ADC2/A2), LIGHT_SG.2
MD_INPUT: ARDUINO_NANO1.4 (ADC0/A0), METAL_DET.2
unnamed: JP1.5, TETHER_SPARE.1
unnamed: JP1.4, TETHER_SPARE.2
unnamed: JP1.3, TETHER_SPARE.3
unnamed: JP1.2, TETHER_SPARE.4
unnamed: JP1.1, TETHER_SPARE.5
unnamed: ARDUINO_NANO1.28 (D10/OC1B/!SS), BT.1
unnamed: ARDUINO_NANO1.29 (D11/MOSI), WIFI_CN.2
unnamed: ARDUINO_NANO1.30 (D12/MISO), WIFI_CN.1
unnamed: SHORTED.1, SHORTED.2, SHORTED.3, SHORTED.4, SHORTED.5
unnamed: 330_.2, LED4.A
unnamed: 2.2K_VD.1, BT/WIFI_TX.2
unnamed: 1K.2, LED1.A
unnamed: 2.2K_VD1.1, BT/WIFI_TX.1
unnamed: 330.2, LED3.A
unnamed: 12V_INPUT.TRM_1, 12V_INPUT.TRM_2, IN_FUSE.2
PH_INPUT: ARDUINO_NANO1.11 (ADC7/A7), PH.2
PRES_INPUT: ARDUINO_NANO1.10 (ADC6/A6), PRESSURE.2
PWM_1: ARDUINO_NANO1.27 (D9/OC1A), BT.2, CYTRON.4
PWM_2: ARDUINO_NANO1.23 (D5/T1), CYTRON.2, DG_SPARE.2
SOL1_SG: ARDUINO_NANO1.9 (ADC5/SCL/A5), SOL_SG.1
SOL2_SG: ARDUINO_NANO1.8 (ADC4/SDA/A4), SOL_SG.2
SOL3_SG: ARDUINO_NANO1.7 (ADC3/A3), SOL_SG.3
STATE: BLUETOOTH.1
TEMP_INPUT: ARDUINO_NANO1.1 (SCK/D13), PUR.1, TEMP.2
WIFI_RX: 1K_VD1.1, 2.2K_VD1.2, VD_BT/WIFI.2

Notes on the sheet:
Input + Output Pins
Signals + Sensors
BT + Cytron
ARDUINO
Voltage Divider ( for Communication )
Camera Signals
Tether
Board 3

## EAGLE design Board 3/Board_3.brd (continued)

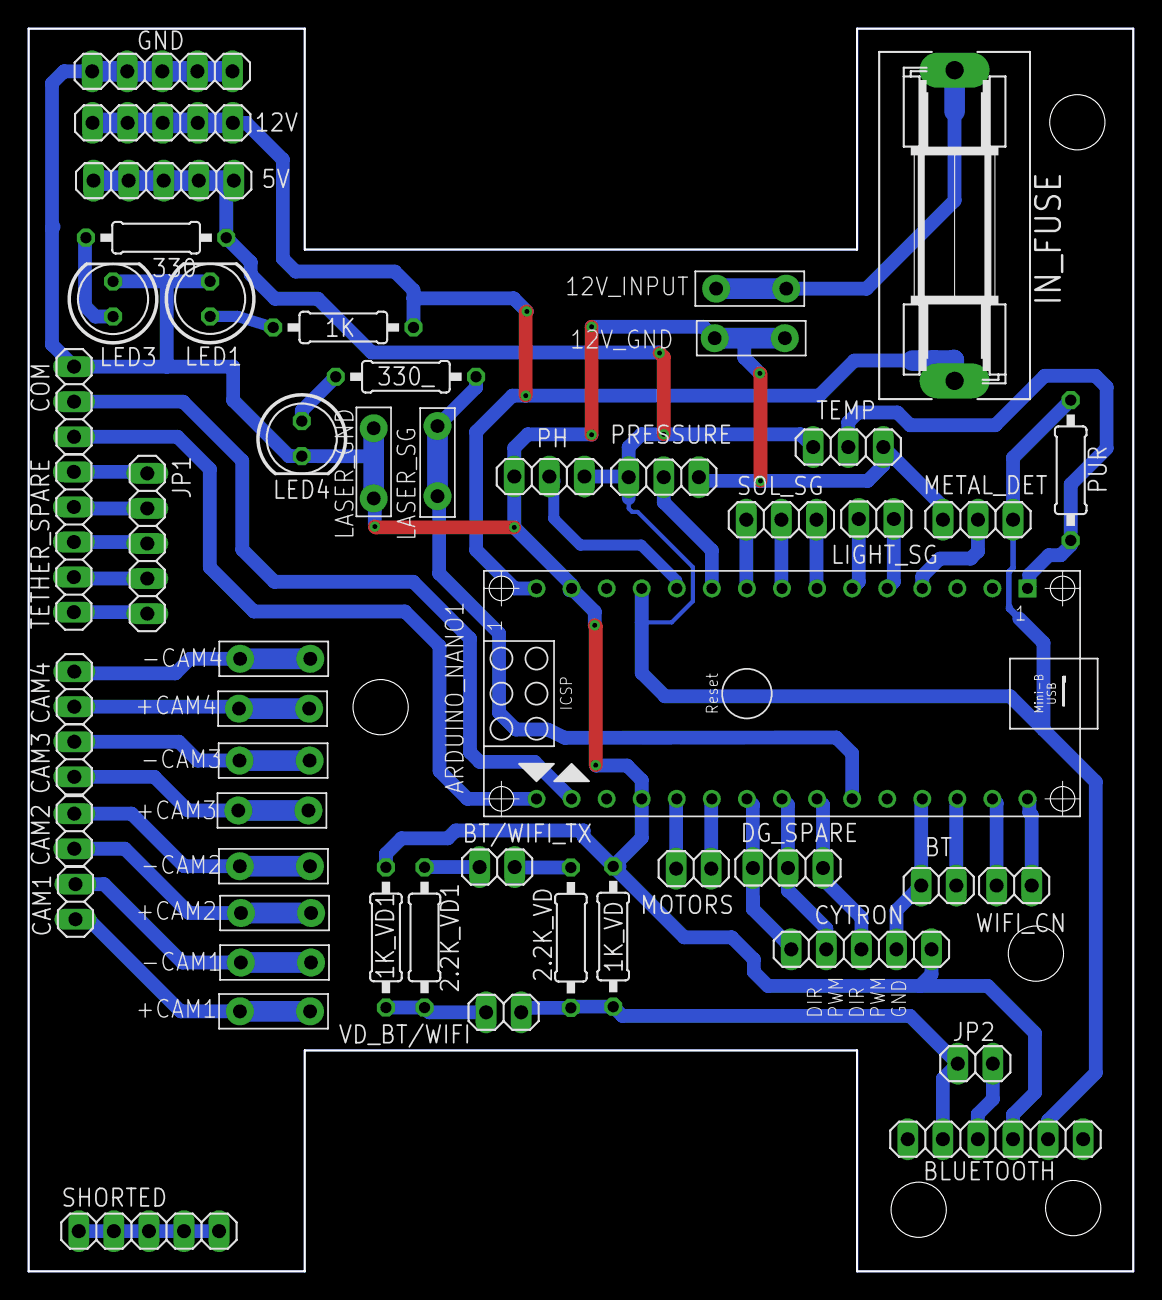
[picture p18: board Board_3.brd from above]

Board: 2 copper layers, 80.0 x 90.0 mm, 51 parts (0 on the bottom side), 47 nets.
